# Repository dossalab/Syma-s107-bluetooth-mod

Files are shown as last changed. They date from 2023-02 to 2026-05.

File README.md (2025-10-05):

## Syma S107 Bluetooth mod

Syma S107 is a toy helicopter model being popular in early-2010s. It's rather well known because of its low cost, good flying characteristics and sturdy body resistant to crashes.

The original remote control system uses infrared communication - similar to how classic TV remotes work. The major drawback of such solution is that it's very sensitive to direct sunlight - making it very hard (and even slightly dangerous) to fly this toy outside. This also requires keeping a dedicated remote which is larger than this toy and always tend to go missing :)

This is a complete redesign of original motherboard, featuring Bluetooth LE with broader range and smartphone compatibility, battery charger with USB port and battery level reporting, additional outputs and custom, hackable firmware!

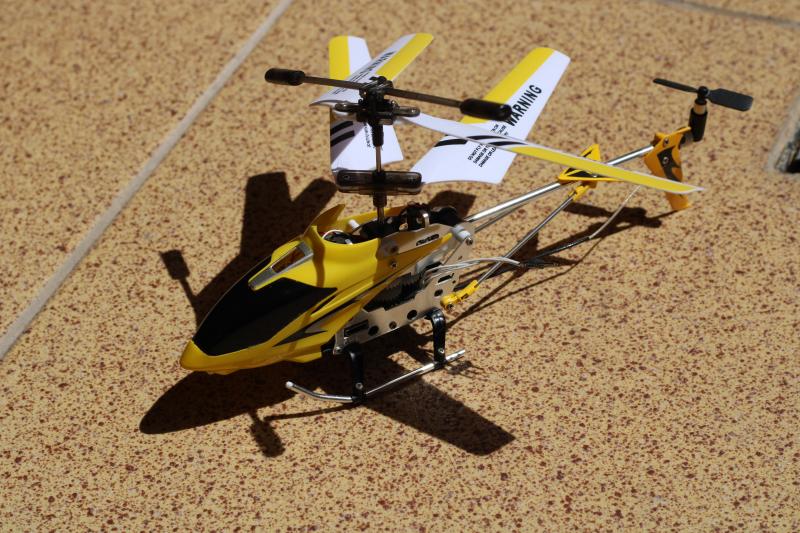
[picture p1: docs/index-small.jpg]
title image


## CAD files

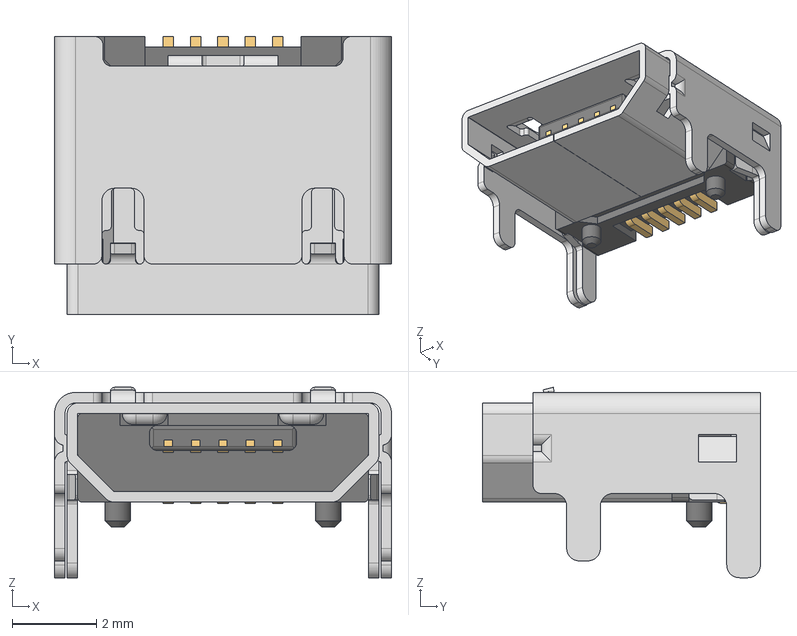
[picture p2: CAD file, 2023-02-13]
hardware/3d/629105150521.stp
8.00 x 6.60 x 4.52 mm
629105150521_Housing
629105150521_Pin1 x 4
629105150521_Pin2
629105150521_Shielding2
629105150521_Shielding

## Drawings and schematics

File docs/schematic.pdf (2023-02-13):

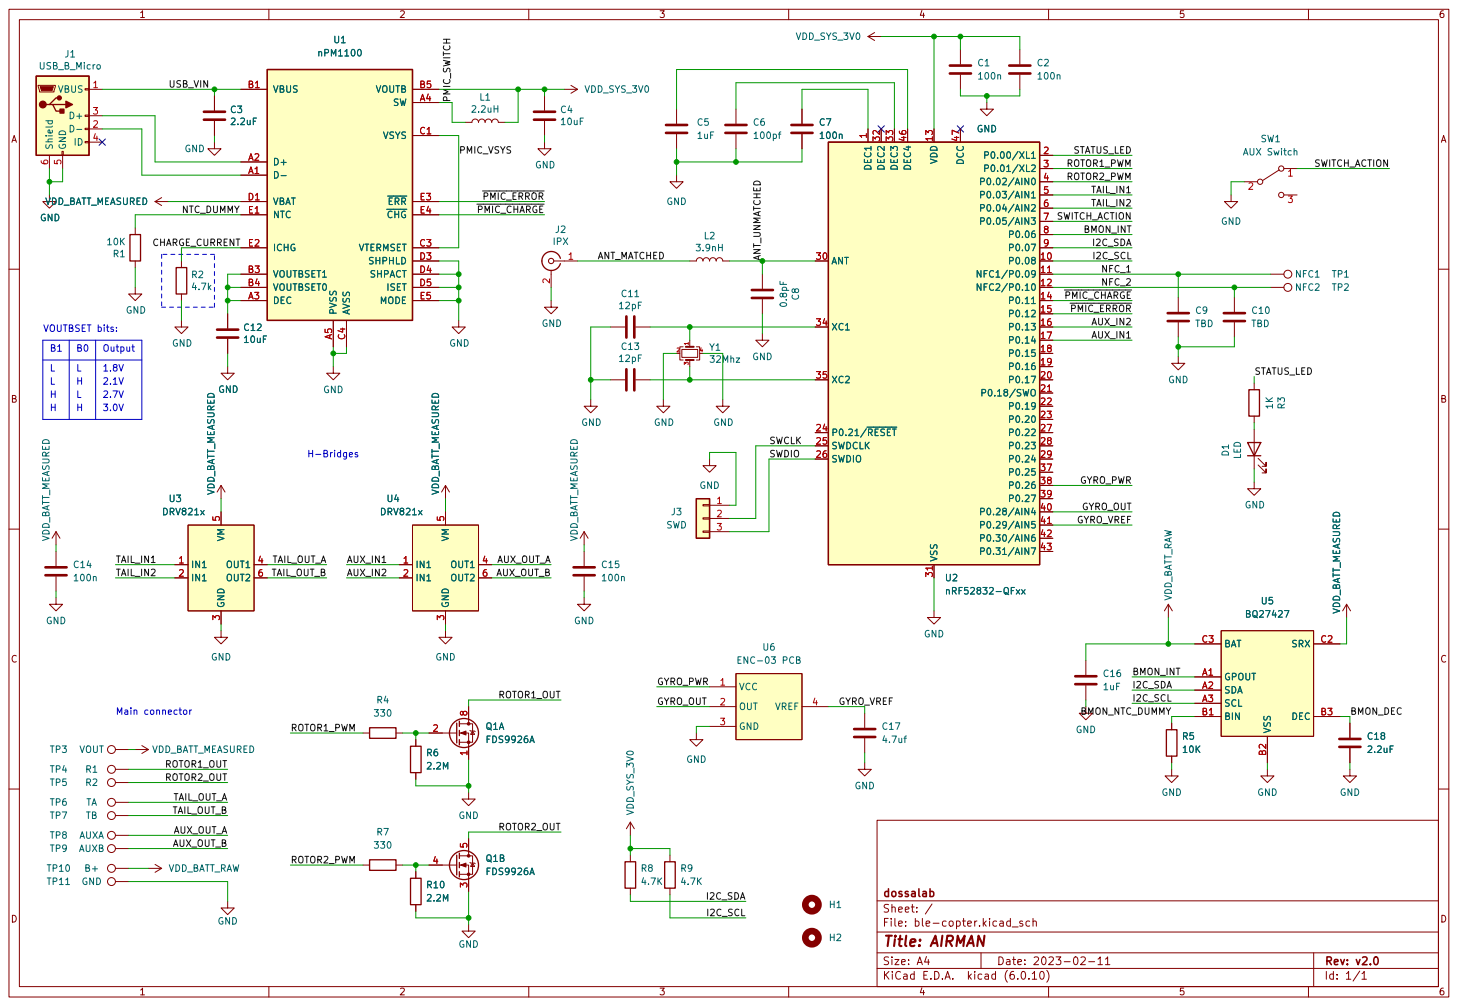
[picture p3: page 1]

1 P0.08 10 NFC1/P0.09 11 NFC2/P0.10 12 VDD 13 P0.11 14 P0.12 15 P0.13 16 P0.14 17 P0.15 18 P0.16 19 P0.00/XL1 2 P0.17 20 P0.18/SWO 21 P0.19 22 P0.20 23 P0.21/~{RESET} 24 SWDCLK 25 SWDIO 26 P0.22 27 P0.23 28 P0.24 29 P0.01/XL2 3 ANT 30 VSS 31 DEC2 32 DEC3 33 XC1 34 XC2 35 P0.25 37 P0.26 38 P0.27 39 P0.02/AIN0 4 P0.28/AIN4 40 P0.29/AIN5 41 P0.30/AIN6 42 P0.31/AIN7 43 DEC4 46 DCC 47 P0.03/AIN1 5 P0.04/AIN2 6 P0.05/AIN3 7 P0.06 8 P0.07 9 U2

1 P0.08 10 NFC1/P0.09 11 NFC2/P0.10 12 VDD 13 P0.11 14 P0.12 15 P0.13 16 P0.14 17 P0.15 18 P0.16 19 P0.00/XL1 2 P0.17 20 P0.18/SWO 21 P0.19 22 P0.20 23 P0.21/~{RESET} 24 SWDCLK 25 SWDIO 26 P0.22 27 P0.23 28 P0.24 29 P0.01/XL2 3 ANT 30 VSS 31 DEC2 32 DEC3 33 XC1 34 XC2 35 P0.25 37 P0.26 38 P0.27 39 P0.02/AIN0 4 P0.28/AIN4 40 P0.29/AIN5 41 P0.30/AIN6 42 P0.31/AIN7 43 DEC4 46 DCC 47 P0.03/AIN1 5 P0.04/AIN2 6 P0.05/AIN3 7 P0.06 8 P0.07 9 VDD_BATT_MEASURED

B1 | B0 | Output H
L H | L | 2.1V 2.7V H

File: ble-copter.kicad_sch Sheet: / dossalab GND

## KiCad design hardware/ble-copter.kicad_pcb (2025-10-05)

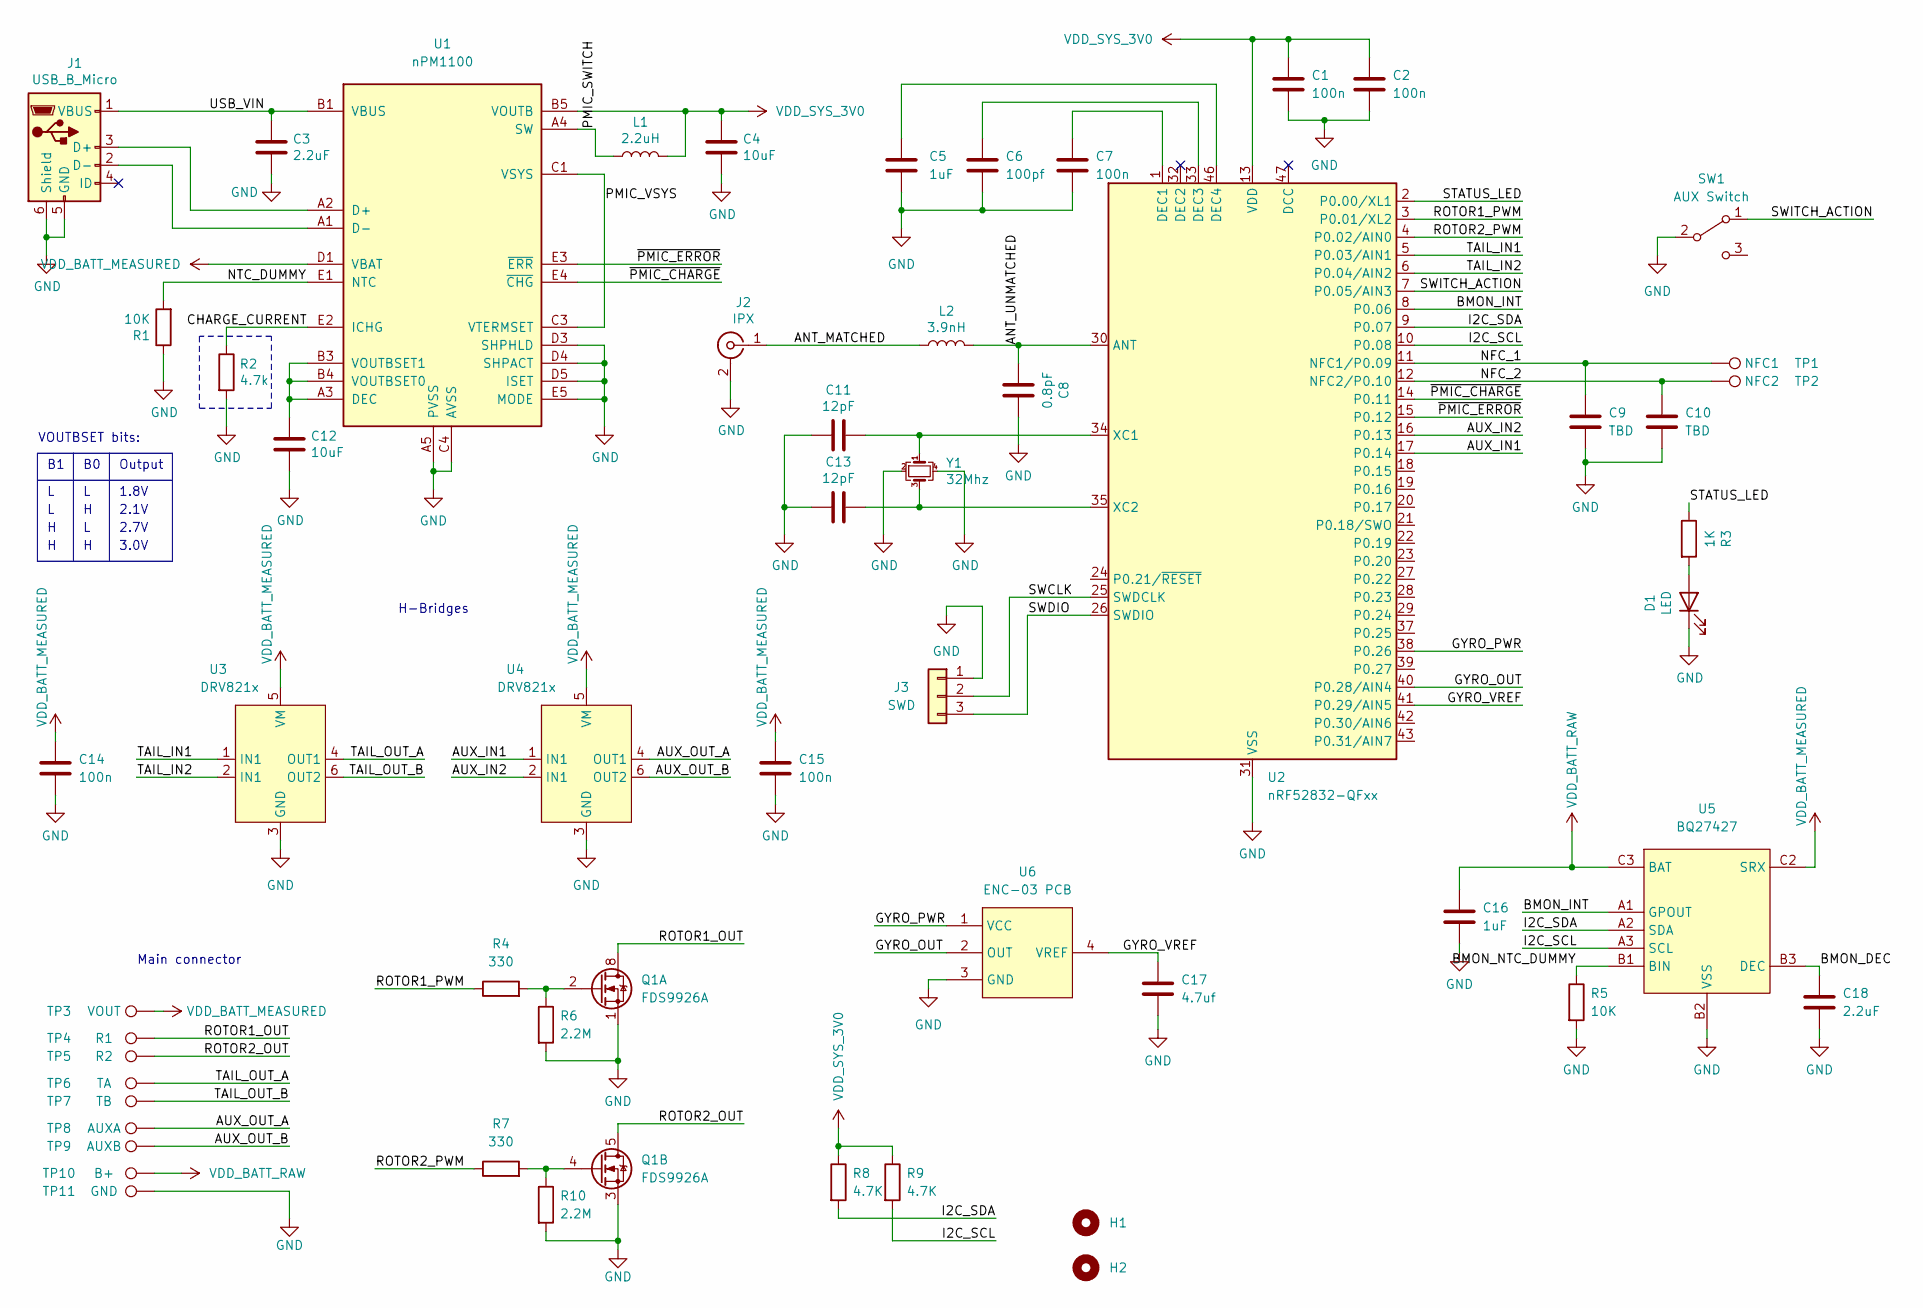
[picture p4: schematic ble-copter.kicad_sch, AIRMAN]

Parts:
C1, C2, C7, C14, C15: 100n; C_0603_1608Metric
C3, C18: 2.2uF; C_0603_1608Metric
C4, C12: 10uF; C_0603_1608Metric
C5, C16: 1uF; C_0603_1608Metric
C6: 100pf; C_0603_1608Metric
C8: 0.8pF; C_0603_1608Metric
C9, C10: TBD; C_0603_1608Metric
C11, C13: 12pF; C_0603_1608Metric
C17: 4.7uf; C_0603_1608Metric
D1: LED; LED_0603_1608Metric
H1, H2: MountingHole; MountingHole_1.6mm
J1: USB_B_Micro; USB_Micro-B_Wuerth_629105150521
J2: IPX; U.FL_Hirose_U.FL-R-SMT-1_Vertical
J3: SWD; PinHeader_1x03_P1.27mm_Vertical
L1: 2.2uH; L_0805_2012Metric
L2: 3.9nH; L_0603_1608Metric
Q1: FDS9926A; SOIC-8_3.9x4.9mm_P1.27mm
R1, R5: 10K; R_0603_1608Metric
R2: 4.7k; R_0603_1608Metric
R3: 1K; R_0603_1608Metric
R4, R7: 330; R_0603_1608Metric
R6, R10: 2.2M; R_0603_1608Metric
R8, R9: 4.7K; R_0603_1608Metric
SW1: AUX Switch; SW_SPDT_PCM12
TP1: NFC1; TestPoint_THTPad_D1.0mm_Drill0.5mm
TP2: NFC2; TestPoint_THTPad_D1.0mm_Drill0.5mm
TP3: VOUT; TestPoint_THTPad_D1.0mm_Drill0.5mm
TP4: R1; TestPoint_THTPad_D1.0mm_Drill0.5mm
TP5: R2; TestPoint_THTPad_D1.0mm_Drill0.5mm
TP6: TA; TestPoint_THTPad_D1.0mm_Drill0.5mm
TP7: TB; TestPoint_THTPad_D1.0mm_Drill0.5mm
TP8: AUXA; TestPoint_THTPad_D1.0mm_Drill0.5mm
TP9: AUXB; TestPoint_THTPad_D1.0mm_Drill0.5mm
TP10: B+; TestPoint_THTPad_D1.0mm_Drill0.5mm
TP11: GND; TestPoint_THTPad_D1.0mm_Drill0.5mm
U1: nPM1100; Nordic_WLCSP-25_5x5_2.075x2.075mm
U2: nRF52832-QFxx; QFN-48-1EP_6x6mm_P0.4mm_EP4.6x4.6mm
U3, U4: DRV821x; SOT-563
U5: BQ27427; BGA-9_3x3_1.6x1.6mm
U6: ENC-03 PCB
Y1: 32Mhz; Crystal_SMD_2520-4Pin_2.5x2.0mm

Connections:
/ANT_MATCHED: J2.1 (In), L2.1
/ANT_UNMATCHED: C8.2, L2.2, U2.30 (ANT)
/AUX_IN1: U2.17 (P0.14), U4.1 (IN1)
/AUX_IN2: U2.16 (P0.13), U4.2 (IN1)
/AUX_OUT_A: TP8.1, U4.4 (OUT1)
/AUX_OUT_B: TP9.1, U4.6 (OUT2)
/BMON_DEC: C18.1, U5.B3 (DEC)
/BMON_INT: U2.8 (P0.06), U5.A1 (GPOUT)
/BMON_NTC_DUMMY: R5.1, U5.B1 (BIN)
/CHARGE_CURRENT: R2.1, U1.E2 (ICHG)
/GYRO_OUT: U2.40 (P0.28/AIN4), U6.2 (OUT)
/GYRO_PWR: U2.38 (P0.26), U6.1 (VCC)
/GYRO_VREF: C17.1, U2.41 (P0.29/AIN5), U6.4 (VREF)
/I2C_SCL: R9.2, U2.10 (P0.08), U5.A3 (SCL)
/I2C_SDA: R8.2, U2.9 (P0.07), U5.A2 (SDA)
/NFC_1: C9.1, TP1.1, U2.11 (NFC1/P0.09)
/NFC_2: C10.1, TP2.1, U2.12 (NFC2/P0.10)
/NTC_DUMMY: R1.2, U1.E1 (NTC)
/PMIC_SWITCH: L1.1, U1.A4 (SW)
/PMIC_VSYS: U1.C1 (VSYS), U1.C2 (VSYS), U1.C3 (VTERMSET)
/ROTOR1_OUT: Q1.7 (D1), Q1.8 (D1), TP4.1
/ROTOR1_PWM: R4.1, U2.3 (P0.01/XL2)
/ROTOR2_OUT: Q1.5 (D2), Q1.6 (D2), TP5.1
/ROTOR2_PWM: R7.1, U2.4 (P0.02/AIN0)
/STATUS_LED: R3.1, U2.2 (P0.00/XL1)
/SWCLK: J3.2, U2.25 (SWDCLK)
/SWDIO: J3.3, U2.26 (SWDIO)
/SWITCH_ACTION: SW1.1 (A), U2.7 (P0.05/AIN3)
/TAIL_IN1: U2.5 (P0.03/AIN1), U3.1 (IN1)
/TAIL_IN2: U2.6 (P0.04/AIN2), U3.2 (IN1)
/TAIL_OUT_A: TP6.1, U3.4 (OUT1)
/TAIL_OUT_B: TP7.1, U3.6 (OUT2)
/~PMIC_CHARGE: U1.E4 (~CHG), U2.14 (P0.11)
/~PMIC_ERROR: U1.E3 (~ERR), U2.15 (P0.12)
GND: C1.2, C2.2, C3.2, C4.2, C5.2, C6.2, C7.2, C8.1, C9.2, C10.2, C11.2, C12.2, C13.2, C14.2, C15.2, C16.2, C17.2, C18.2, D1.1 (K), J1.5 (GND), J1.6 (Shield), J2.2 (Ext), J3.1, Q1.1 (S1), Q1.3 (S2), R1.1, R2.2, R5.2, R6.2, R10.2, SW1.2 (B), TP11.1, U1.A5 (PVSS), U1.C4 (AVSS), U1.C5 (AVSS), U1.D3 (SHPHLD), U1.D4 (SHPACT), U1.D5 (ISET), U1.E5 (MODE), U2.31 (VSS), U2.45 (VSS), U2.49 (VSS), U3.3 (GND), U4.3 (GND), U5.B2 (VSS), U5.C1 (VSS), U6.3 (GND), Y1.2, Y1.4
unnamed: C5.1, U2.46 (DEC4)
unnamed: C6.1, U2.33 (DEC3)
unnamed: C7.1, U2.1 (DEC1)
unnamed: C11.1, U2.34 (XC1), Y1.1
unnamed: C12.1, U1.A3 (DEC), U1.B3 (VOUTBSET1), U1.B4 (VOUTBSET0)
unnamed: C13.1, U2.35 (XC2), Y1.3
unnamed: D1.2 (A), R3.2
unnamed: J1.2 (D-), U1.A1 (D-)
unnamed: J1.3 (D+), U1.A2 (D+)
unnamed: Q1.2 (G1), R4.2, R6.1
unnamed: Q1.4 (G2), R7.2, R10.1
VBAT: C14.1, C15.1, TP3.1, U1.D1 (VBAT), U1.D2 (VBAT), U3.5 (VM), U4.5 (VM), U5.C2 (SRX)
VBUS: C3.1, J1.1 (VBUS), U1.B1 (VBUS), U1.B2 (VBUS)
VDD_BATT_RAW: C16.1, TP10.1, U5.C3 (BAT)
VDD_SYS_3V0: C1.1, C2.1, C4.1, L1.2, R8.1, R9.1, U1.B5 (VOUTB), U2.13 (VDD), U2.36 (VDD), U2.48 (VDD)

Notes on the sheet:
Output
2.1V
VOUTBSET bits:
Main connector
H-Bridges
2.7V
3.0V
1.8V

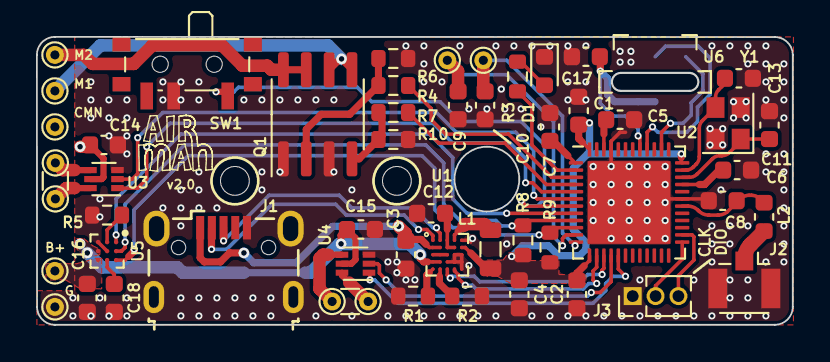
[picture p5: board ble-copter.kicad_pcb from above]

Board: 2 copper layers, 42.0 x 16.0 mm, 56 parts (0 on the bottom side), 50 nets.

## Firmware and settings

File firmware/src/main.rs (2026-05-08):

#![no_std]
#![no_main]

use assign_resources::assign_resources;
use embassy_embedded_hal::shared_bus::asynch::i2c::I2cDevice;
use state::SystemState;
use static_cell::StaticCell;

use core::panic::PanicInfo;
use embassy_executor::Spawner;
use embassy_nrf::{
    bind_interrupts,
    interrupt::{self, InterruptExt},
    peripherals, saadc,
    twim::{self, Twim},
    Peri,
};
use embassy_sync::{blocking_mutex::raw::NoopRawMutex, mutex::Mutex};
use git_version::git_version;
use nrf_softdevice::{raw, Softdevice};

use defmt::{info, unwrap};

mod ble;
mod control;
mod executor;
mod indications;
mod power;
mod state;
mod types;
mod utils;
mod xbox;

use defmt_rtt as _;

type SharedI2cBus = Mutex<NoopRawMutex, Twim<'static>>;
type SharedI2cDevice<'a> = I2cDevice<'a, NoopRawMutex, Twim<'a>>;

bind_interrupts!(struct Irqs {
    TWISPI0 => twim::InterruptHandler<peripherals::TWISPI0>;
    SAADC => saadc::InterruptHandler;
});

assign_resources! {
    led_switch: LedSwitchResources {
        led: P0_00,
        switch: P0_05,
        pwm: PWM1
    },
    i2c: I2cResources {
        // make sure to check interrupt priority below if changing
        i2c: TWISPI0,
        sda: P0_07,
        scl: P0_08,
    },
    power: PowerResources {
        fuelgauge_int: P0_06,
        charging_int: P0_11,
        fault_int: P0_12
    },
    controller: ControllerResources {
        // in current implementation, there's no need to share them, so just
        // keep them here for simplicity
        adc: SAADC,
        pwm: PWM0,

        rotor1: P0_01,
        rotor2: P0_02,
        tail_p: P0_03,
        tail_n: P0_04,
        gyro_power: P0_26,
        gyro_input: P0_28,
        gyro_vref: P0_29,
    },
}

// It's safer to reboot rather than hang
#[panic_handler]
fn panic(_info: &PanicInfo) -> ! {
    cortex_m::peripheral::SCB::sys_reset();
}

fn hw_init() -> (AssignedResources, &'static mut Softdevice) {
    let mut config = embassy_nrf::config::Config::default();

    /*
     * Softdevice implicitly utilizes the highest-level interrupt priority
     * We have to move all other interrupts to lower priority, unless
     * random issues and asserts from the Softdevice may (and will) occur
     */
    config.gpiote_interrupt_priority = interrupt::Priority::P2;
    config.time_interrupt_priority = interrupt::Priority::P2;

    interrupt::TWISPI0.set_priority(interrupt::Priority::P2);
    interrupt::SAADC.set_priority(interrupt::Priority::P2);

    let sd_config = nrf_softdevice::Config {
        common_vs_uuid: Some(raw::ble_common_cfg_vs_uuid_t { vs_uuid_count: 15 }),
        conn_gap: Some(raw::ble_gap_conn_cfg_t {
            conn_count: 2,
            event_length: 24,
        }),
        ..nrf_softdevice::Config::default()
    };

    let p = embassy_nrf::init(config);
    let sd = Softdevice::enable(&sd_config);

    (split_resources!(p), sd)
}

fn make_shared_i2c(r: I2cResources) -> &'static SharedI2cBus {
    const BUFFER_LEN: usize = 64;

    static BUS: StaticCell<SharedI2cBus> = StaticCell::new();
    static BUFFER: StaticCell<[u8; BUFFER_LEN]> = StaticCell::new();

    let i2c = Twim::new(
        r.i2c,
        Irqs,
        r.sda,
        r.scl,
        twim::Config::default(),
        BUFFER.init([0; BUFFER_LEN]),
    );

    BUS.init(Mutex::new(i2c))
}

#[embassy_executor::main(executor = "executor::MwuWorkaroundExecutor")]
async fn main(spawner: Spawner) {
    let (r, sd) = hw_init();
    let i2c = make_shared_i2c(r.i2c);

    info!("ble-copter ({}) is running. Hello!", git_version!());

    static SYSTEM_STATE: StaticCell<SystemState> = StaticCell::new();
    let system_state = SYSTEM_STATE.init(SystemState::new());

    spawner.spawn(unwrap!(indications::run(system_state, r.led_switch)));
    spawner.spawn(unwrap!(ble::run(sd, system_state)));
    spawner.spawn(unwrap!(control::run(system_state, r.controller,)));
    spawner.spawn(unwrap!(power::run(system_state, r.power, i2c)));
    spawner.spawn(unwrap!(state::run(system_state)));
}

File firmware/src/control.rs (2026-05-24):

use defmt::{info, unwrap};
use embassy_futures::select::{select3, Either3};
use embassy_nrf::{
    gpio::{self, Level, Output, OutputDrive},
    pwm::{self, DutyCycle, SimplePwm},
    saadc::{self, Saadc},
};
use embassy_time::{Duration, Ticker, Timer};
use pid::Pid;

use crate::{
    ble::types::Configuration, state::SystemState, types::JoystickData, utils, xbox,
    ControllerResources, Irqs,
};

struct Controller<'a> {
    pwm: SimplePwm<'a>,
    adc: Saadc<'a, 1>,
    _gyro_power: gpio::Output<'a>,
    tail_n: gpio::Output<'a>,
    pid: Pid<f32>,
    input: JoystickData,
    gyro_offset: i32,
    yaw_expo: f32,
}

/// Applies an expo (exponential) curve to a joystick axis value.
///
/// `expo` in [0.0, 1.0]: 0 = fully linear, 1 = fully cubic.
/// The curve blends linear and cubic response, which softens sensitivity
/// near center while preserving full deflection at the edges.
fn apply_expo(value: i32, max: i32, expo: f32) -> i32 {
    let n = value as f32 / max as f32;
    let curved = n * ((1.0 - expo) + expo * n * n);
    (curved * max as f32) as i32
}

impl<'a> Controller<'a> {
    const PWM_MAX_DUTY: u16 = 512;
    const PID_CONTROL_LIMIT: u16 = Self::PWM_MAX_DUTY / 2;
    const RECEIVE_TIMEOUT: Duration = Duration::from_secs(1);
    /// Max yaw axis value after the >> 6 shift applied in tick().
    const YAW_STICK_MAX: i32 = xbox::STICKS_RANGE / 2 >> 6;

    fn set_pwm(&mut self, r1: i32, r2: i32, v: i32) {
        let clamp_to_pwm = |x: i32| x.clamp(0, Self::PWM_MAX_DUTY as i32) as u16;

        let tail = if v > 0 {
            self.tail_n.set_high();

            Self::PWM_MAX_DUTY as i32 - v
        } else {
            self.tail_n.set_low();
            -v
        };

        let duties = [
            DutyCycle::inverted(clamp_to_pwm(r1)),
            DutyCycle::inverted(clamp_to_pwm(r2)),
            DutyCycle::inverted(clamp_to_pwm(tail)),
            DutyCycle::inverted(0), // unused
        ];

        self.pwm.set_all_duties(duties);
    }

    async fn read_angular_speed(&mut self) -> f32 {
        let mut buf = [0; 1];

        self.adc.sample(&mut buf).await;

        // ADC equations are:
        // Vdiff (volts) = reading * 0.6 / (gain * 2^resolution-1) = reading * 0.6 / 2048
        // speed = Vdiff (volts) * 1000 / 0.67 = Vdiff * 600 / (2048 * 0.67)

        let val = buf[0] as i32 + self.gyro_offset;
        val as f32 * 600.0 / (2048.0 * 0.5 * 0.67)
    }

    async fn tick(&mut self) {
        let throttle = (self.input.j1.1 >> 6).max(0);
        let yaw_raw = self.input.j2.0 >> 6;
        let yaw = apply_expo(yaw_raw, Self::YAW_STICK_MAX, self.yaw_expo);

        let control = if throttle > 10 {
            let ang_rate = self.read_angular_speed().await;

            self.pid.setpoint = -yaw as f32;
            self.pid.next_control_output(ang_rate).output as i32
        } else {
            0
        };

        let rotor1 = throttle + control;
        let rotor2 = throttle - control;
        let elevator = self.input.j2.1 >> 6;

        self.set_pwm(rotor1, rotor2, elevator);
    }

    fn add_input(&mut self, jd: JoystickData) {
        self.input = jd;
    }

    fn apply_config(&mut self, config: Configuration) {
        self.pid
            .p(config.p, Self::PID_CONTROL_LIMIT)
            .i(config.i, Self::PID_CONTROL_LIMIT)
            .d(config.d, Self::PID_CONTROL_LIMIT);
        self.yaw_expo = config.yaw_expo.clamp(0.0, 1.0);
    }

    async fn init(r: &'a mut ControllerResources, config: Configuration) -> Self {
        let mut pwm_config = pwm::SimpleConfig::default();

        pwm_config.max_duty = Controller::PWM_MAX_DUTY;
        pwm_config.prescaler = pwm::Prescaler::Div16;

        let mut adc_config = saadc::Config::default();

        adc_config.resolution = saadc::Resolution::_12bit;
        adc_config.oversample = saadc::Oversample::Over4x;

        let mut adc_channel_config =
            saadc::ChannelConfig::differential(r.gyro_input.reborrow(), r.gyro_vref.reborrow());

        // Some considerations here:
        // - gyro vref is 1.35v, our ADC vref is 600 mV;
        // - 0.67 mV per deg/s;
        // - maximum angular velocity is 300 deg/s, which is ~200 mV;
        // - however, some natural DC offset seem to be taking place, so we need wider range

        adc_channel_config.time = saadc::Time::_40US;
        adc_channel_config.gain = saadc::Gain::Gain1_2;

        let pwm = SimplePwm::new_3ch(
            r.pwm.reborrow(),
            // Recheck channel id assignments above if changing order
            r.rotor1.reborrow(),
            r.rotor2.reborrow(),
            r.tail_p.reborrow(),
            &pwm_config,
        );

        let adc = saadc::Saadc::new(r.adc.reborrow(), Irqs, adc_config, [adc_channel_config]);
        let gyro_power = Output::new(r.gyro_power.reborrow(), Level::High, OutputDrive::Standard);
        let tail_n = Output::new(r.tail_n.reborrow(), Level::Low, OutputDrive::Standard);

        adc.calibrate().await;

        // Give gyro some time to settle
        Timer::after_millis(50).await;

        let mut s = Self {
            adc,
            _gyro_power: gyro_power,
            pwm,
            tail_n,
            pid: Pid::new(0.0, Self::PWM_MAX_DUTY),
            input: Default::default(),
            gyro_offset: 742,
            yaw_expo: 0.0,
        };

        s.apply_config(config);
        s
    }
}

#[embassy_executor::task]
pub async fn run(state: &'static SystemState, mut r: ControllerResources) {
    let mut config_receiver = unwrap!(state.config.receiver());
    let mut controller_sample_receiver = unwrap!(state.controller_sample.receiver());
    let controller_run_allowed_receiver = unwrap!(state.controller_run_allowed.receiver());

    let run_controller = async || {
        info!("running controller");

        const CONTROL_LOOP_RATE: Duration = Duration::from_hz(200);

        let initial_config = config_receiver.try_get().unwrap_or_default();
        let mut controller = Controller::init(&mut r, initial_config).await;
        let mut ticker = Ticker::every(CONTROL_LOOP_RATE);

        loop {
            match select3(
                config_receiver.changed(),
                controller_sample_receiver.changed(),
                ticker.next(),
            )
            .await
            {
                Either3::First(config) => controller.apply_config(config),
                Either3::Second(input) => controller.add_input(input),
                Either3::Third(_) => controller.tick().await,
            }
        }
    };

    utils::run_with_receiver(controller_run_allowed_receiver, run_controller).await;
}

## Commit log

2023-02-13 init commit
    [629105150521.stp, ble-copter.kicad_pcb, ble-copter.kicad_sch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]
2023-02-13 add schematics as a pdf
2025-10-05 Kicad 9.0
    [ble-copter.kicad_pcb, ble-copter.kicad_sch]
2025-10-05 move pcb to a separate directory
    [629105150521.stp, ble-copter.kicad_pcb, ble-copter.kicad_sch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]
2025-10-05 basic charge monitoring
2025-10-05 bring fuelgauge driver
2025-10-05 more power related work
2025-10-11 add mwu high current consumption workaround
    [main.rs]
2025-10-23 make sure controller drops PWM on disconnection
2025-10-25 do not use PWM sequencer for indications
    power saving - use simple timer blinky
2025-10-25 unite fuelgauge and charger resources
2025-10-25 set I2C interrupt priority
2025-10-25 use shared i2c bus
2025-11-05 increase base frequency for PWM
    less audible noise, smoother operation
    [control.rs]
2025-11-05 fix the pwm-inverted issue
    upstream embassy fixed the inverted pwm! so we can now switch away from
    the fork
    [control.rs]
2025-11-05 print fuelgauge initialization error
    [power.rs]
2025-11-08 revisit the power system
2025-11-20 set PWM divider to 16
    divider 1 does not work well for tail's motor H-Bridge. TI!
    [control.rs]
2025-11-23 advertise the power service to help with scanning
2025-11-23 get some gyroscope data
2025-11-30 better controller + pid
2025-11-30 rename powerstats -> systemstate
2026-02-01 host requests support for fuelgauge reset and firmware restart
    [control.rs, power.rs]
2026-02-01 make sure CC gain is set correctly after user-induced reset
    [power.rs]
2026-05-08 power state machine fixes (claude)
    [power.rs]
2026-05-21 switch to code generation for gatt, switch to floats for PID
2026-05-21 controller connection state + scanner state + ratable + small notification rework
    [power.rs]
2026-05-21 expo for yaw
2026-05-23 combine expo settings with pid settings under a new configuration service
